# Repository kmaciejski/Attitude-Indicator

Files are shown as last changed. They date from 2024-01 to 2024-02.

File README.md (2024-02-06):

# Summary
The main purpose of this work was to design and build an electronic artificial horizon. The theoretical part of the work contains a short description and technical specification of two different EFSI instruments.
After analyzing the constructions existing on the market, the electronic components included in the designed device were selected.
The ESP32 microcontroller with cooperating elements has been described.
After completing the theoretical part of the work, a step-by-step procedure for designing the electrical, mechanical and software parts of the device was presented.
Finally, the device was completed and tested. 
The project includes: determining hardware requirements, selecting electronic components, drawing up an electrical diagram, designing a PCB, writing software, modeling a housing adapted to the PCB, assembling and testing the device.

# Technology Stack
- ESP32
- ESP-IDF
- RTOS
- LVGL
- Altium Designer
- SolidWorks

## Main screen



## 3D Model




## PCB Model




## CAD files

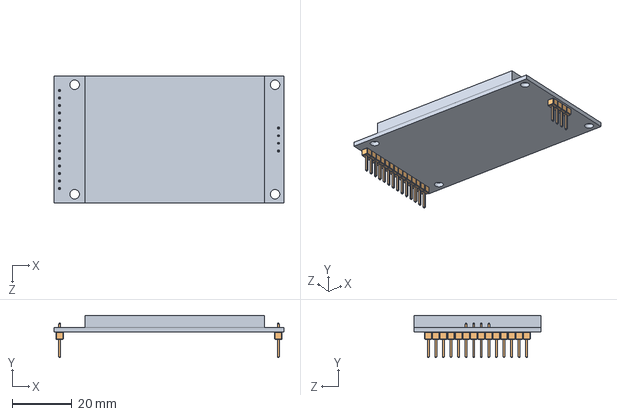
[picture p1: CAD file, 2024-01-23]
Solidworks/LCD module/LCD module.SLDASM
77.2 x 14.2 x 42.7 mm
Lcd board
goldpin 2.54 x 2

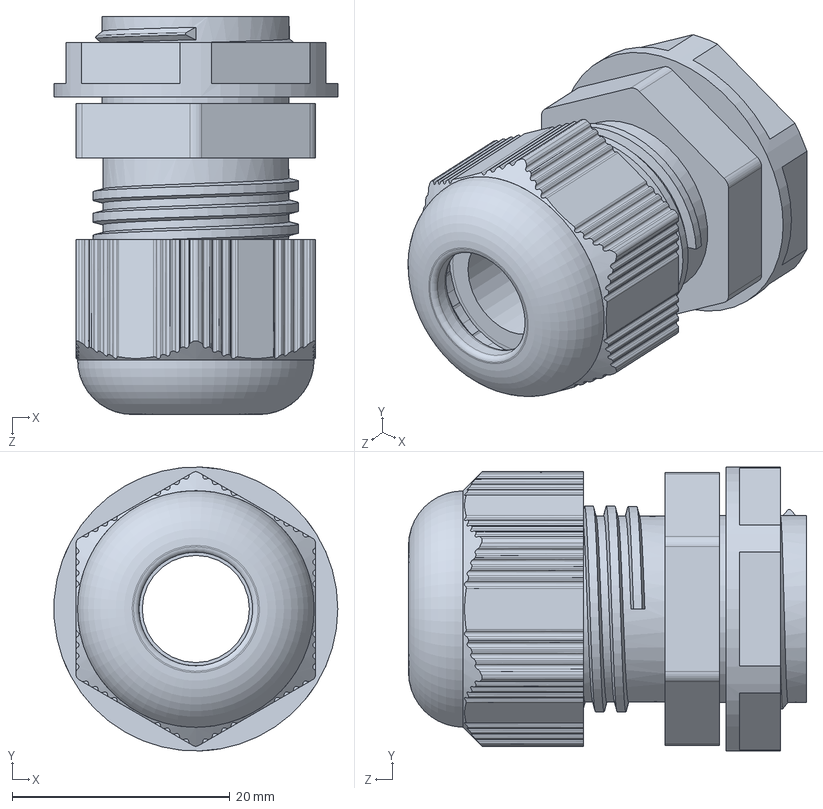
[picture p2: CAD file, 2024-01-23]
Solidworks/9002.SLDPRT
26.1 x 26.1 x 36.6 mm

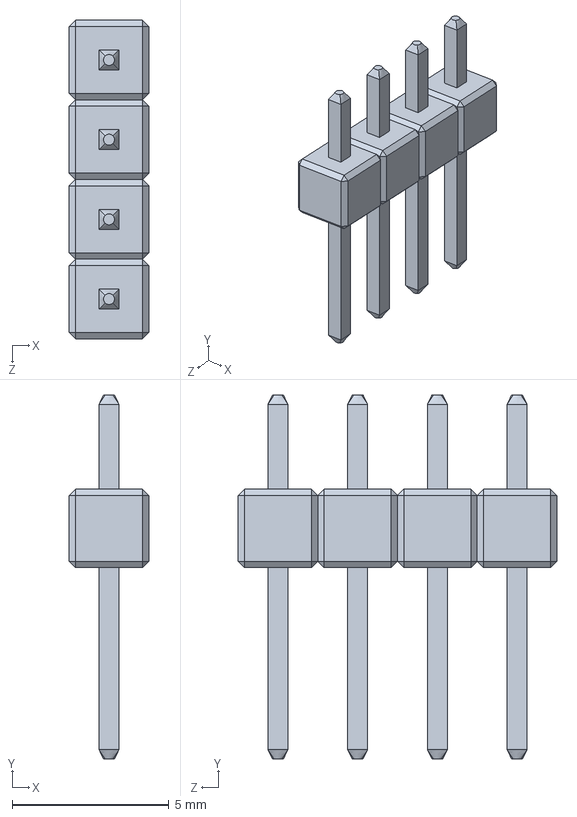
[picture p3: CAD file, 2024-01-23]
Solidworks/LCD module/goldpin 2.54.SLDPRT
2.54 x 11.6 x 10.2 mm

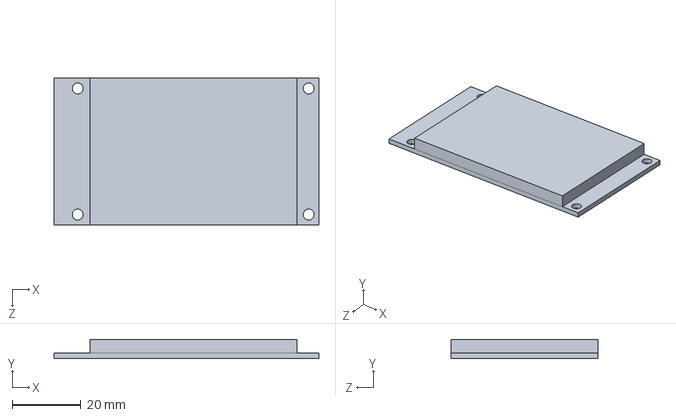
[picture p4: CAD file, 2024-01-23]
Solidworks/LCD module/Lcd board.SLDPRT
77.2 x 5.60 x 42.7 mm

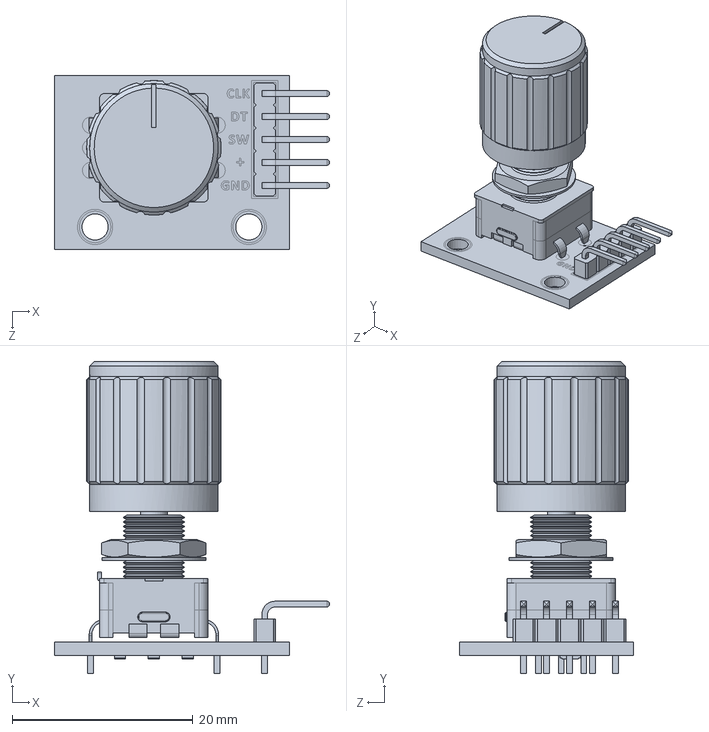
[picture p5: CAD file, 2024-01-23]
Solidworks/SW2019 Rotary Encoder Knob Module.SLDPRT
30.4 x 34.5 x 19.2 mm

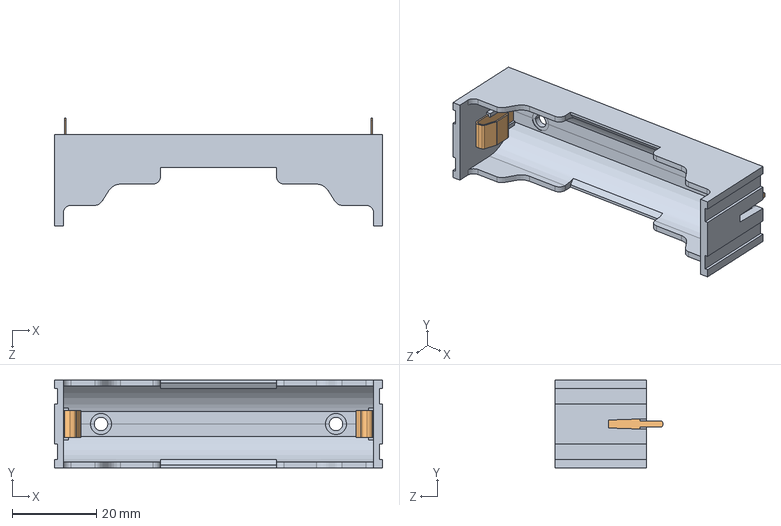
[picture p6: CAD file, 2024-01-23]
Solidworks/Battery holder/18650 Full.SLDASM
77.7 x 20.8 x 25.5 mm
18650m
18650s x 2

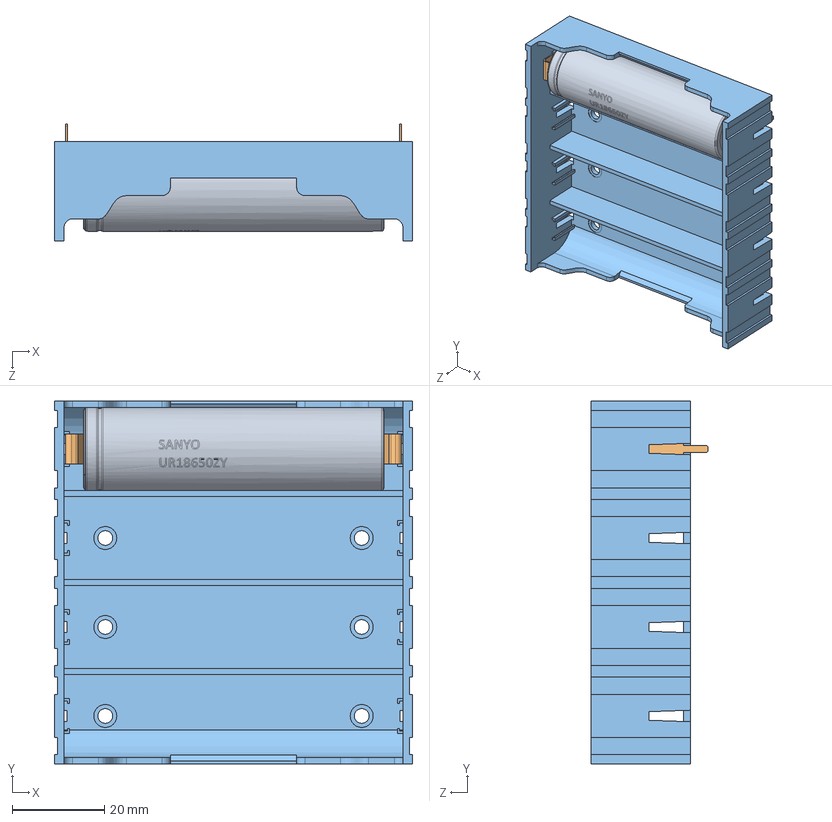
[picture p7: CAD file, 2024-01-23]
Solidworks/Battery holder/18650 Full - modified.SLDASM
77.7 x 78.7 x 25.5 mm
18650m
18650s x 2

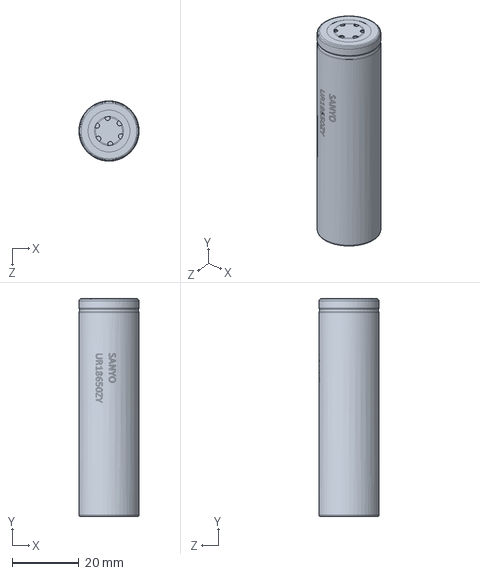
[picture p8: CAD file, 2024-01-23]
Solidworks/Battery holder/18650.SLDPRT
18.0 x 65.1 x 18.0 mm

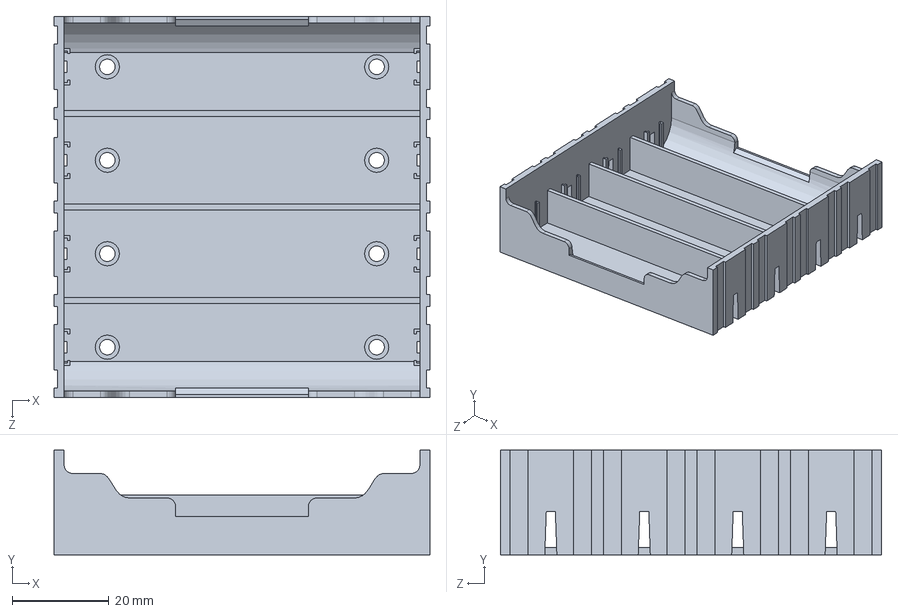
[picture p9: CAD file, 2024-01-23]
Solidworks/Battery holder/18650m.SLDPRT
77.7 x 21.6 x 78.7 mm

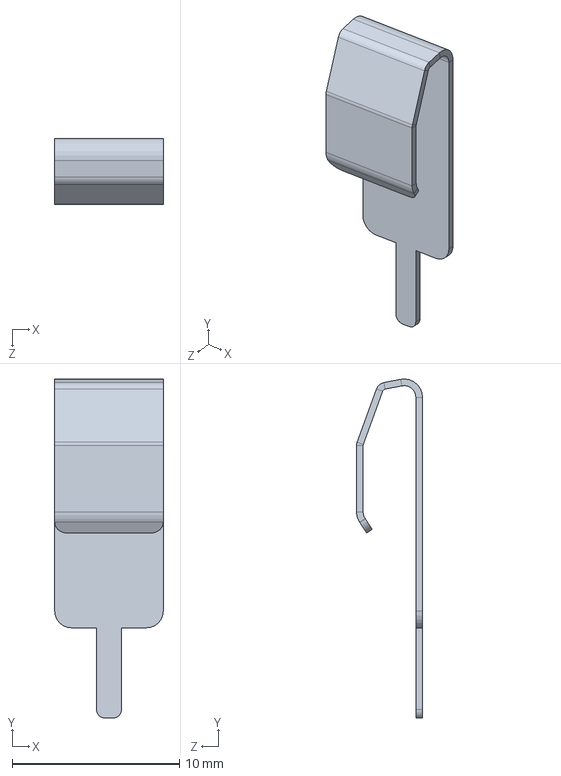
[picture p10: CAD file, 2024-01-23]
Solidworks/Battery holder/18650s.SLDPRT
6.50 x 20.3 x 3.96 mm

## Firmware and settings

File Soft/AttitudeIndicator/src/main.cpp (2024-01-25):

#include <Arduino.h>
#include "PowerModule.hpp"
#include "Sensors.hpp"
#include "UI.hpp"
#include <ESP32Encoder.h>

// Definicje modułów
PowerModule pm;
Sensors sensors;
UI ui;
ESP32Encoder encoder;

/*
    Callback obsługujący zdarzenie przycisku enkodera
*/
void onButtonAction(ClickType_t ct){

  switch(ct){

    case HOLD:
      ui.setScreen(Screen_t::SCREEN_SELECTION); // Przełącz ekran na ekran wyboru (menu główne)
      break;

    case SHUTDOWN :
      ui.setScreen(Screen_t::SCREEN_SHUTDOWN);  // Przełącz ekran na ekran wyłączenia
      break;

  }

}

void setup() {

  Serial.begin(9600);
  Serial.println("Starting . . .");

  sensors.begin();

  pm.begin(GPIO_NUM_27, GPIO_NUM_32, GPIO_NUM_34, GPIO_NUM_35);

  encoder.attachSingleEdge ( GPIO_NUM_25, GPIO_NUM_26 );
  encoder.useInternalWeakPullResistors = UP;
  encoder.setCount (0);
  encoder.setFilter(1000);

  ui.begin();
  pm.setPowerClickListener(onButtonAction);
}

// Aktualizacje modułów w wątku głównym (M.T.)
void loop() {
  sensors.loop();
  pm.loop();
  ui.loop(encoder.getCount(), pm, sensors);
}

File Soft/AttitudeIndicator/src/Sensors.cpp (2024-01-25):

#include "Sensors.hpp"
#include <Arduino.h>
#include <Wire.h>

#define SAMPLE_PERIOD (0.01f) // replace this with actual sample period

FusionAhrs        Sensors::ahrs;
Adafruit_MPU6050  Sensors::mpu;
Adafruit_BMP280   Sensors::bmp(&Wire);
DFRobot_QMC5883   Sensors::compass(&Wire, QMC5883_ADDRESS);
SemaphoreHandle_t Sensors::semaphore;
Adafruit_Sensor *Sensors::bmp_temp      = bmp.getTemperatureSensor();
Adafruit_Sensor *Sensors::bmp_pressure  = bmp.getPressureSensor();

AttitiudeInfo_t   Sensors::attitiude{0};
AttitiudeInfo_t   Sensors::st_attitiude{0};

uint32_t Sensors::qnh_hpa;   // QNH
float Sensors::temperature = 25.0f;
float Sensors::pressureHPa = 1013.25f;
float Sensors::altitude_ft = 400.0f;
float Sensors::vertical_speed_fpm = 0.0f;

uint32_t Sensors::st_qnh_hpa;   // QNH
float Sensors::st_temperature = 25.0f;
float Sensors::st_pressureHPa = 1013.25f;
float Sensors::st_vertical_speed_fpm = 0.0f;
float Sensors::st_altitude_ft = 400.0f;

/*
  Funkcja obliczająca i filtrująca prędkość pionową na podstawie zmian ciśnienia w czasie
*/
float calculateNFilterFpm(float pressure_hPa){

  static float prev_fpm = 0.0;                            // Poprzednia wartość wznoszenia [ft/min]
  static float prev_pressure_hPa = 1013.25f;              // Poprzednia wartość ciśnienia statycznego [hPa]
  static volatile unsigned long prev_millis = millis();   // Poprzedni czas od uruchomienia [ms]

  unsigned volatile long curr_millis = millis();                          // Aktualny czas od uruchomienia [ms]
  unsigned volatile long delta_ms = curr_millis - prev_millis;            // delta t [ms]
  
  if (delta_ms >= 1000){ // 1s sampling

    // Przeliczamy wartości ciśnienia statycznego na wysokości w stopach [ft]
    float prev_abs_altitude_ft = ( (44330 * 3.280839895) * (1.0 - pow(prev_pressure_hPa / 1013.25f, 0.1903f)) );
    float abs_altitude_ft = ( (44330 * 3.280839895) * (1.0 - pow(pressure_hPa / 1013.25f, 0.1903f)) );

    float delta_altitude_ft = abs_altitude_ft - prev_abs_altitude_ft;     // delta H [ft]
    float fpm = (delta_altitude_ft * 1000.0f * 60.0f) / (float)delta_ms;  // obliczanie fpm [ft/min]
  
    // Próg 100 ft/min (poniżej próbki są odrzucane i predkosc pionowa wynosi 0)
    if (fpm > 100.0f || fpm < -100.0f)
      prev_fpm = fpm;
    else
      prev_fpm = 0.0f;

    prev_pressure_hPa = pressure_hPa;   // Aktualizujemy poprzednią wartość ciśnienia
    prev_millis = curr_millis;          // Aktualizujemy poprzedni czas od uruchomienia
  }

  return prev_fpm;    // Zwracamy obliczone wznoszenie [ft/min]
}

/*
    Zadanie S.M.
        - odczytuje napiecie baterii poprzez ADC
        - debouncing i wykrywanie stanu przycisku
*/
void Sensors::sensors_module_task(void* arg)
{

  TickType_t xLastWakeTime;
  const TickType_t xFrequency = 75 / portTICK_PERIOD_MS;
  BaseType_t xWasDelayed;
  xLastWakeTime = xTaskGetTickCount ();

  unsigned long millisPrev = millis();
  unsigned long delta = 0;
  sensors_event_t a, g, mpu_temp, bmp_temp_event, bmp_pressure_event;

  while(1){

    // Odczyt z 3 czujników IMU :
    mpu.getEvent(&a, &g, &mpu_temp);
    sVector_t mag = compass.readRaw();

    // Obliczanie położenia przestrzennego
    const FusionVector gyroscope = {g.gyro.x, g.gyro.y, g.gyro.z};
    const FusionVector accelerometer = {a.acceleration.x, a.acceleration.y, a.acceleration.z};
    const FusionVector magnetometer = {mag.XAxis, mag.YAxis, mag.ZAxis};

    delta = millis() - millisPrev;
    millisPrev = millis();

    FusionAhrsUpdate(&ahrs, gyroscope, accelerometer, magnetometer, ((float)delta) / 1000);
    const FusionEuler euler = FusionQuaternionToEuler(FusionAhrsGetQuaternion(&ahrs));

    bmp_temp->getEvent(&bmp_temp_event);
    bmp_pressure->getEvent(&bmp_pressure_event);

    if ( xSemaphoreTake(semaphore, portMAX_DELAY) == pdTRUE ){  // Aktualizacja zmiennych

      st_attitiude.pitch   = std::roundf(euler.angle.pitch);
      st_attitiude.roll    = std::roundf(euler.angle.roll);
      st_attitiude.hdg     = std::roundf(euler.angle.yaw + 180.0f);
      
      st_temperature = bmp_temp_event.temperature;
      st_pressureHPa = bmp_pressure_event.pressure;
      st_altitude_ft = (44330 * 3.280839895) * (1.0 - pow(st_pressureHPa / st_qnh_hpa, 0.1903));
      st_vertical_speed_fpm = calculateNFilterFpm(st_pressureHPa);

      xSemaphoreGive(semaphore);
    }
    
    xTaskDelayUntil( &xLastWakeTime, xFrequency );
  }
}

void Sensors::begin(){

  qnh_hpa = 1025;

  Wire.begin(21, 22, 10000);

 // wireScan();

  initBme();
  initMPU6050();
  initCompas();

  FusionAhrsInitialise(&ahrs);

  semaphore = xSemaphoreCreateBinary();
  xSemaphoreGive(semaphore);

  //start task
  xTaskCreate(sensors_module_task, "sensors_module_task", 2048, NULL, 20, NULL);

}

void Sensors::loop(){

  if(xSemaphoreTake(semaphore, portMAX_DELAY) == pdTRUE){
    memcpy(&attitiude, &st_attitiude, sizeof(AttitiudeInfo_t));

    temperature = st_temperature;                 // Temperatura
    pressureHPa = st_pressureHPa;                 // Ciśnienie BMP
    altitude_ft = st_altitude_ft;                 // Wysokość z uwzględnieniem QNH
    vertical_speed_fpm = st_vertical_speed_fpm;   // Prędkość pionowa
    st_qnh_hpa = qnh_hpa;                         // QNH

    xSemaphoreGive(semaphore);
  }

}

void Sensors::initMPU6050(){

if (!mpu.begin()) {
    Serial.println("Failed to find MPU6050 chip");
    while (1) delay(10);
  }
  Serial.println("MPU6050 Found!");

  mpu.setAccelerometerRange(MPU6050_RANGE_2_G);
  Serial.print("Accelerometer range set to: ");
  switch (mpu.getAccelerometerRange()) {
  case MPU6050_RANGE_2_G:
    Serial.println("+-2G");
    break;
  case MPU6050_RANGE_4_G:
    Serial.println("+-4G");
    break;
  case MPU6050_RANGE_8_G:
    Serial.println("+-8G");
    break;
  case MPU6050_RANGE_16_G:
    Serial.println("+-16G");
    break;
  }
  mpu.setGyroRange(MPU6050_RANGE_250_DEG);
  Serial.print("Gyro range set to: ");
  switch (mpu.getGyroRange()) {
  case MPU6050_RANGE_250_DEG:
    Serial.println("+- 250 deg/s");
    break;
  case MPU6050_RANGE_500_DEG:
    Serial.println("+- 500 deg/s");
    break;
  case MPU6050_RANGE_1000_DEG:
    Serial.println("+- 1000 deg/s");
    break;
  case MPU6050_RANGE_2000_DEG:
    Serial.println("+- 2000 deg/s");
    break;
  }

  mpu.setFilterBandwidth(MPU6050_BAND_94_HZ);
  Serial.print("Filter bandwidth set to: ");
  switch (mpu.getFilterBandwidth()) {
  case MPU6050_BAND_260_HZ:
    Serial.println("260 Hz");
    break;
  case MPU6050_BAND_184_HZ:
    Serial.println("184 Hz");
    break;
  case MPU6050_BAND_94_HZ:
    Serial.println("94 Hz");
    break;
  case MPU6050_BAND_44_HZ:
    Serial.println("44 Hz");
    break;
  case MPU6050_BAND_21_HZ:
    Serial.println("21 Hz");
    break;
  case MPU6050_BAND_10_HZ:
    Serial.println("10 Hz");
    break;
  case MPU6050_BAND_5_HZ:
    Serial.println("5 Hz");
    break;
  }


}

void Sensors::initCompas(){
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

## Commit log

2024-01-23 Solidworks model
    [18650 Full - modified.SLDASM, 18650 Full.SLDASM, 18650.SLDPRT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]
2024-01-25 PCB design
    [Li-Ion Charger.SchDoc, MCU.SchDoc, PCB.PcbDoc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]
2024-01-25 PCB production
